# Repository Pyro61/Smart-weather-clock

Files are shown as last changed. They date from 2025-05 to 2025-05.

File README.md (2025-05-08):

# Smart Weather Clock

A real-time clock system with configurable alarms and integrated weather sensing, built on the STM32G474RE microcontroller. Combines internal and external sensors with a simple user interface and Bluetooth-based data expansion.

---

## Project Goals

This project was developed as a learning exercise with the following goals:

- Practice **bare-metal programming** using direct register access on STM32 microcontrollers
- Design the system so that most tasks are handled via **interrupts**, not the main loop — to reduce power consumption
- Learn to build embedded projects using a **build system (CMake)** instead of IDE-generated Makefiles
- Improve fluency with **Git version control** and good repository structure
- Gain experience in **PCB design**

---

## Features

- Real-Time Clock (RTC) with support for a single configurable alarm
- Weather sensing:
  - **Internal sensors**:
    - Temperature & Pressure: LPS25HB (I2C)
    - Humidity: SHT20 (I2C)
  - **External sensors** (via Bluetooth HC-05):
    - Temperature, Pressure, Humidity, Rain Detection
- Periodic weather update every 10 seconds
- Automatic low-power sleep mode:
  - System enters sleep after completing all tasks in the main loop
  - Wakes up on interrupts (e.g., timer or button press)
- User-selectable weather data source (internal or external)
- Alarm notifications:
  - Display alert
  - External buzzer module with built-in sound generator (controlled via GPIO)
- LCD display: 20x4 alphanumeric, driven by HD44780 controller
- User interface:
  - Push-buttons for navigation and settings
  - Potentiometer for adjusting LCD contrast

---

## Hardware Overview

- **Microcontroller**: STM32G474RE
- **Display**: 20x4 LCD with HD44780 controller (parallel interface)
- **Internal Sensors**:
  - LPS25HB (temperature and pressure, I2C)
  - SHT20 (humidity, I2C)
- **External Sensor Module**:
  - Communicates over UART via HC-05 Bluetooth
  - Sends temperature, pressure, humidity, and rain data
- **Buzzer Module**:
  - External buzzer with internal sound generator
  - Controlled via logic-level GPIO
- **User Inputs**:
  - Buttons:
    - OK / Mode
    - Up
    - Down
    - Left
    - Right
  - Potentiometer for LCD contrast

---

## How It Works

1. On startup, the system initializes:
   - MCU embedded peripherals (RTC, UART, GPIO, RTC etc.)
   - Internal sensors
   - LCD

3. Default behavior after power reset:
   - RTC time = 00:00:00
   - Alarm = disabled
   - Weather readings from internal sensors

4. System behavior:
   - Sensor readings are updated every 10 seconds
   - Every second current time and sensor readings are displayed on the screen
   - After processing all events and interrupts, the system enters low-power mode until the next interrupt

5. The default screen shows:
   - Current time
   - Alarm status
   - Sensor data (internal by default)

6. Pressing **OK / Mode** opens a menu with 4 options. The currently selected option is marked with `>` e.g:
```
   > 1. weather indoor  
     2. weather outdoor  
     3. set time  
     4. set alarm
```

7. Navigation:
   - **Up / Down** to move through options
   - **OK / Mode** to select
   - In `Set Time` and `Set Alarm`:
     - **Left / Right** to move between HH:MM:SS
     - **Up / Down** to adjust values

8. Alarm behavior:
   - When alarm is enabled and the current time matches the alarm:
     - "ALARM" screen is displayed
     - Buzzer is activated via GPIO

---

## User Interface

After system startup and peripheral initialization, the main screen displays:
- Current time (reset to 00:00:00 after power-off — no backup battery for RTC)
- Alarm status (disabled after power reset)
- Live weather readings from internal sensors

### Navigation Summary

- **OK / Mode**: Enter menu / confirm selection
- **Up / Down**: Scroll through menu or increment/decrement values
- **Left / Right**: Switch between hours, minutes, seconds

---

## Getting Started

1. Clone this repository.
2. Build the project using CMake
3. Flash the firmware to STM32G474RE (e.g., Nucleo board).
4. Connect all sensors and peripherals according to the labeled connectors on the [custom PCB](pcb/main_board/main_board_pcb.png) or according to [wiring diagram](pcb/main_board/main_board_schematic.png).

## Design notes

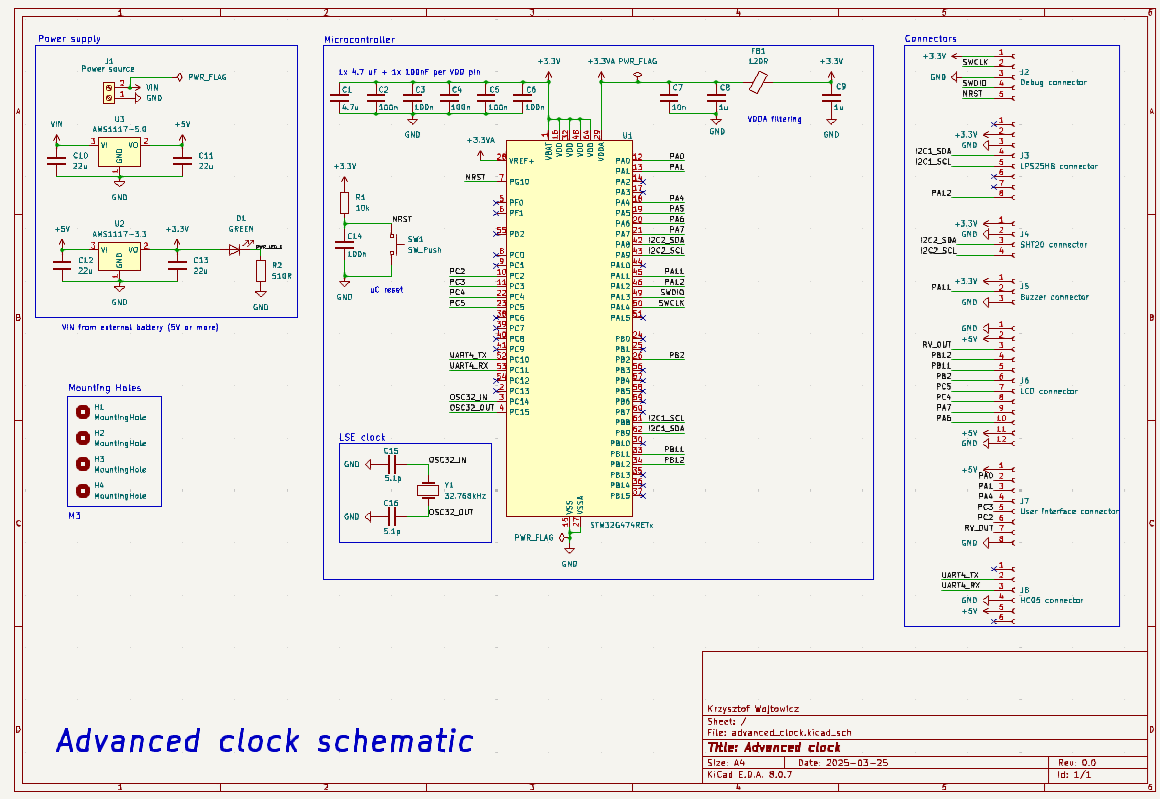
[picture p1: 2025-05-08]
pcb/main_board/main_board_schematic.png

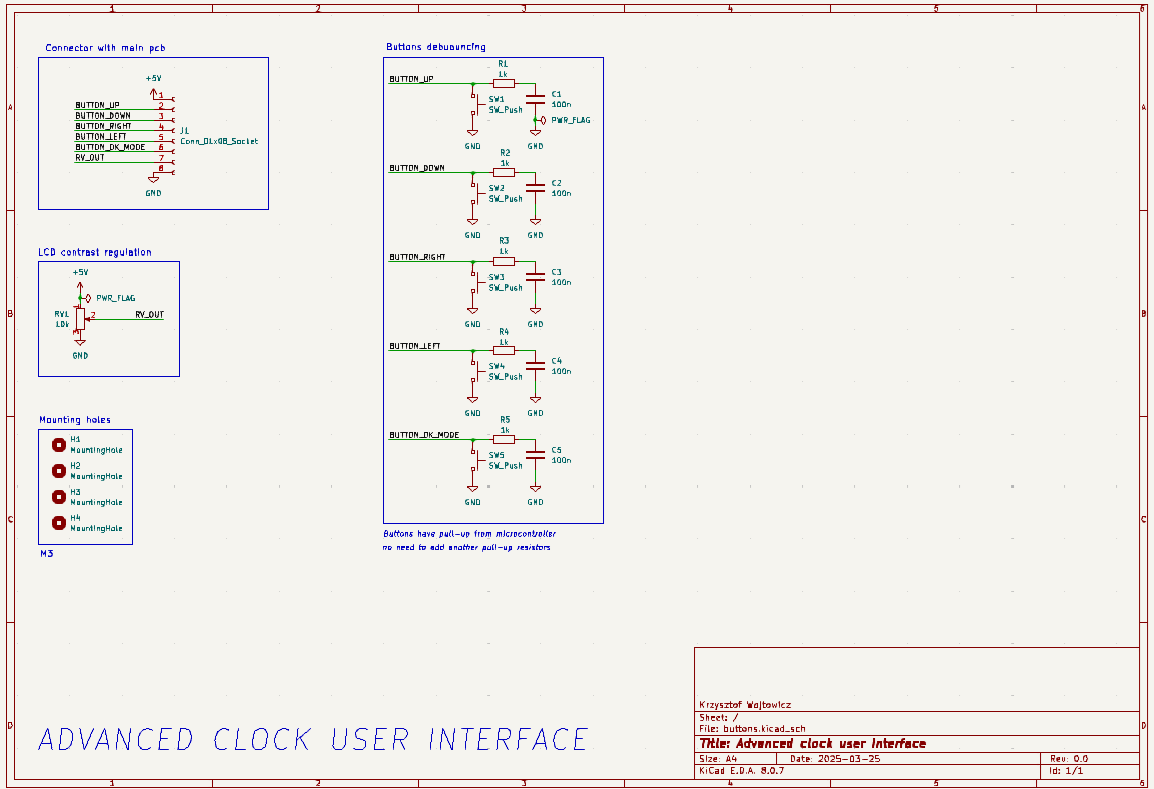
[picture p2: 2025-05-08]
pcb/user_interface_board/user_interface_board_schematic.png

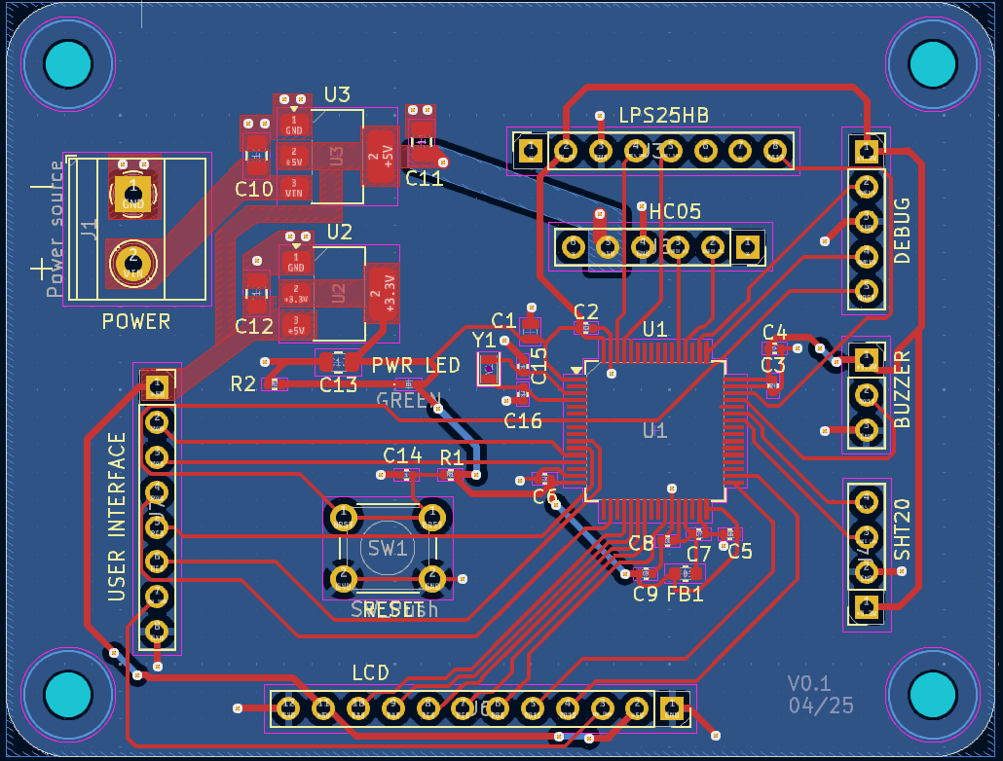
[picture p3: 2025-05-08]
pcb/main_board/main_board_pcb.png

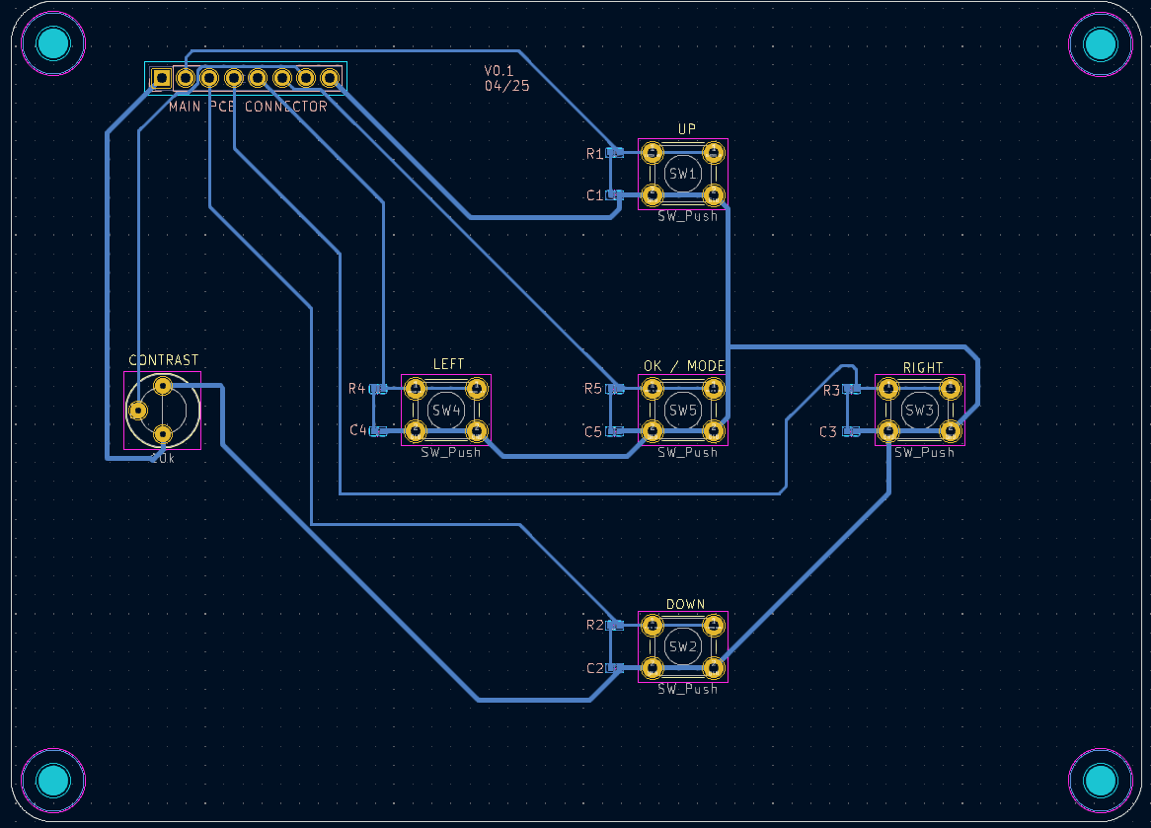
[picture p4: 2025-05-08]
pcb/user_interface_board/user_interface_board_pcb.png

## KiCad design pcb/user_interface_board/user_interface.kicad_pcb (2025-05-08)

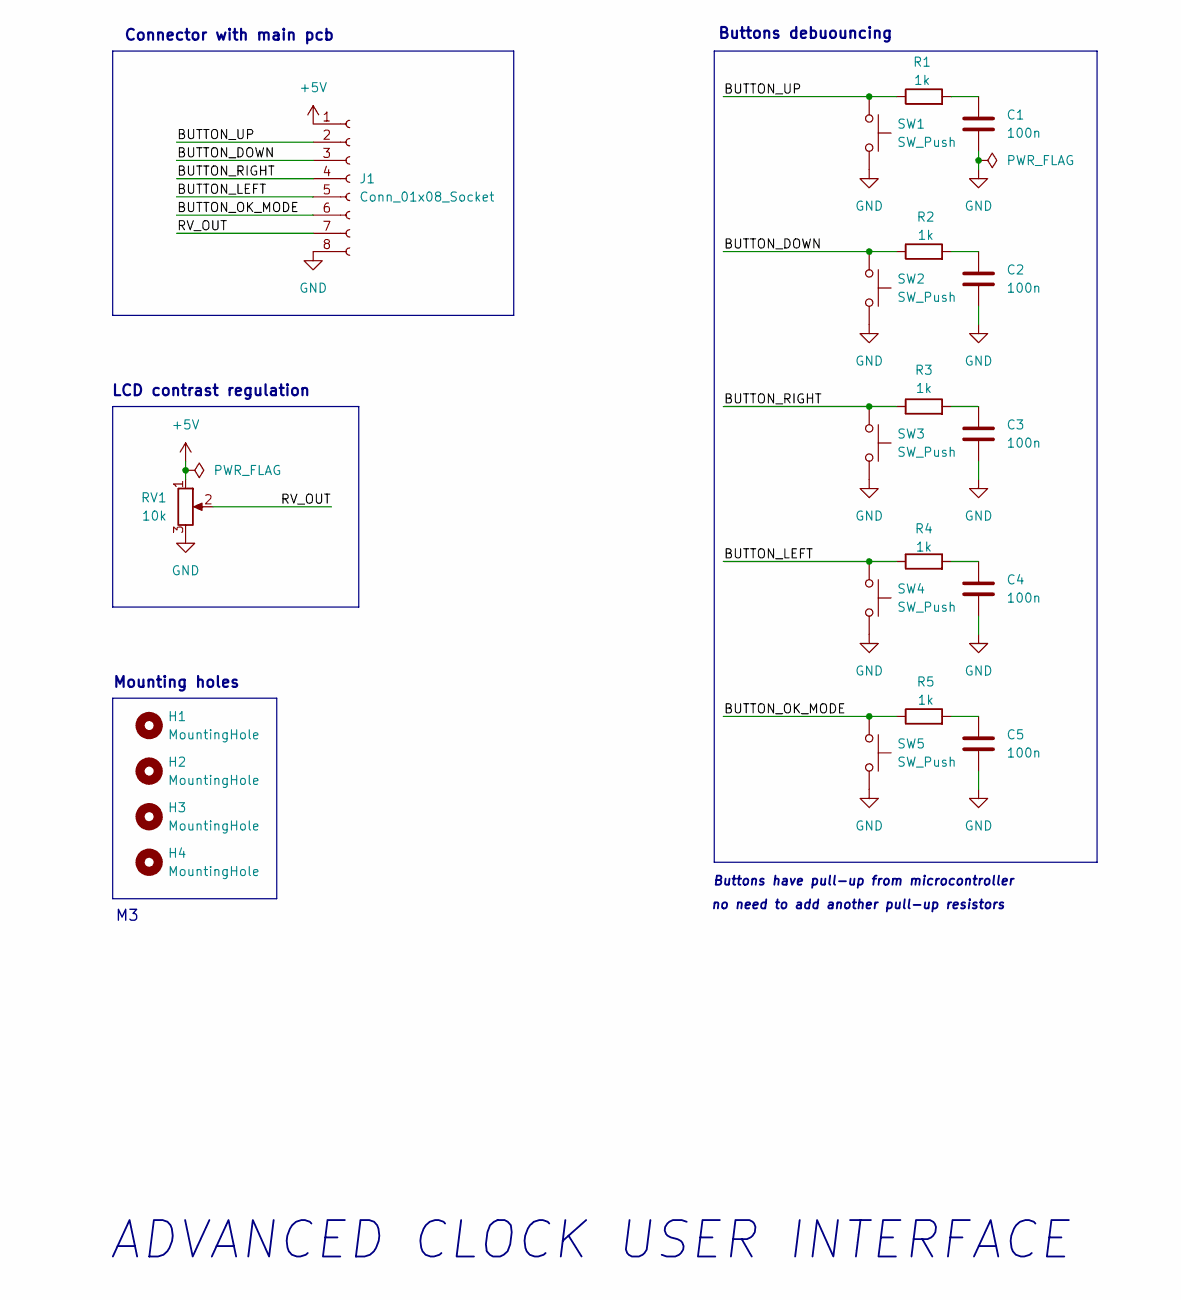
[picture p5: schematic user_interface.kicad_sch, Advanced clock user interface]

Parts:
C1, C2, C3, C4, C5: 100n; C_0402_1005Metric
H1, H2, H3, H4: MountingHole; MountingHole_3.2mm_M3
J1: Conn_01x08_Socket; PinSocket_1x08_P2.54mm_Vertical
R1, R2, R3, R4, R5: 1k; R_0402_1005Metric
RV1: 10k; Potentiometer_Bourns_3339P_Vertical_HandSoldering
SW1, SW2, SW3, SW4, SW5: SW_Push; SW_PUSH_6mm_H7.3mm

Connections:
+5V: J1.1, RV1.1
/BUTTON_DOWN: J1.3, R2.1, SW2.1
/BUTTON_LEFT: J1.5, R4.1, SW4.1
/BUTTON_OK_MODE: J1.6, R5.1, SW5.1
/BUTTON_RIGHT: J1.4, R3.1, SW3.1
/BUTTON_UP: J1.2, R1.1, SW1.1
/RV_OUT: J1.7, RV1.2
GND: C1.2, C2.2, C3.2, C4.2, C5.2, J1.8, RV1.3, SW1.2, SW2.2, SW3.2, SW4.2, SW5.2
unnamed: C1.1, R1.2
unnamed: C2.1, R2.2
unnamed: C3.1, R3.2
unnamed: C4.1, R4.2
unnamed: C5.1, R5.2

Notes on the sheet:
Buttons have pull-up from microcontroller
Mounting holes
LCD contrast regulation
Buttons debuouncing
no need to add another pull-up resistors
Connector with main pcb
ADVANCED CLOCK USER INTERFACE

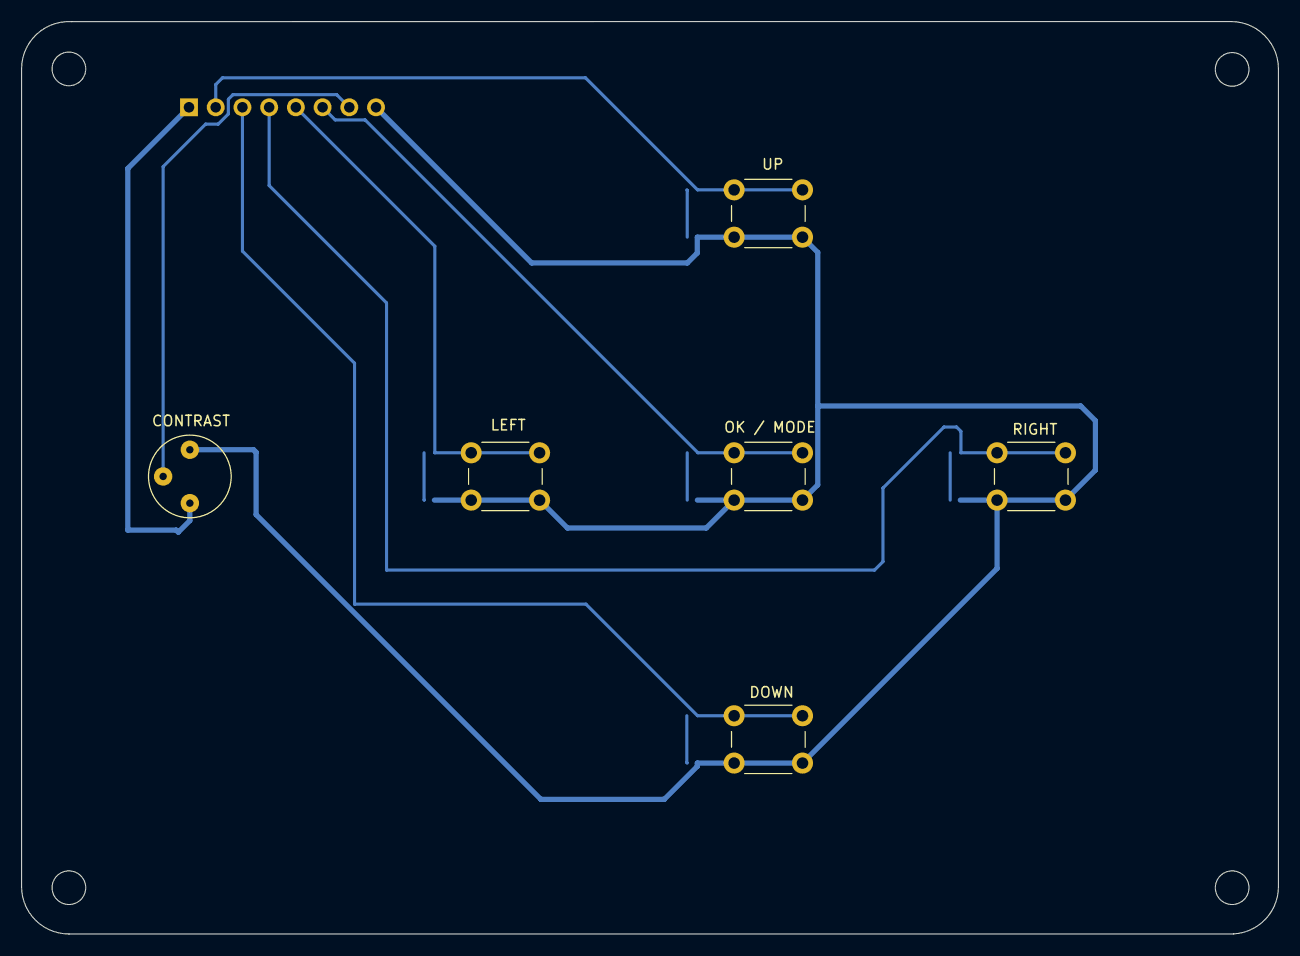
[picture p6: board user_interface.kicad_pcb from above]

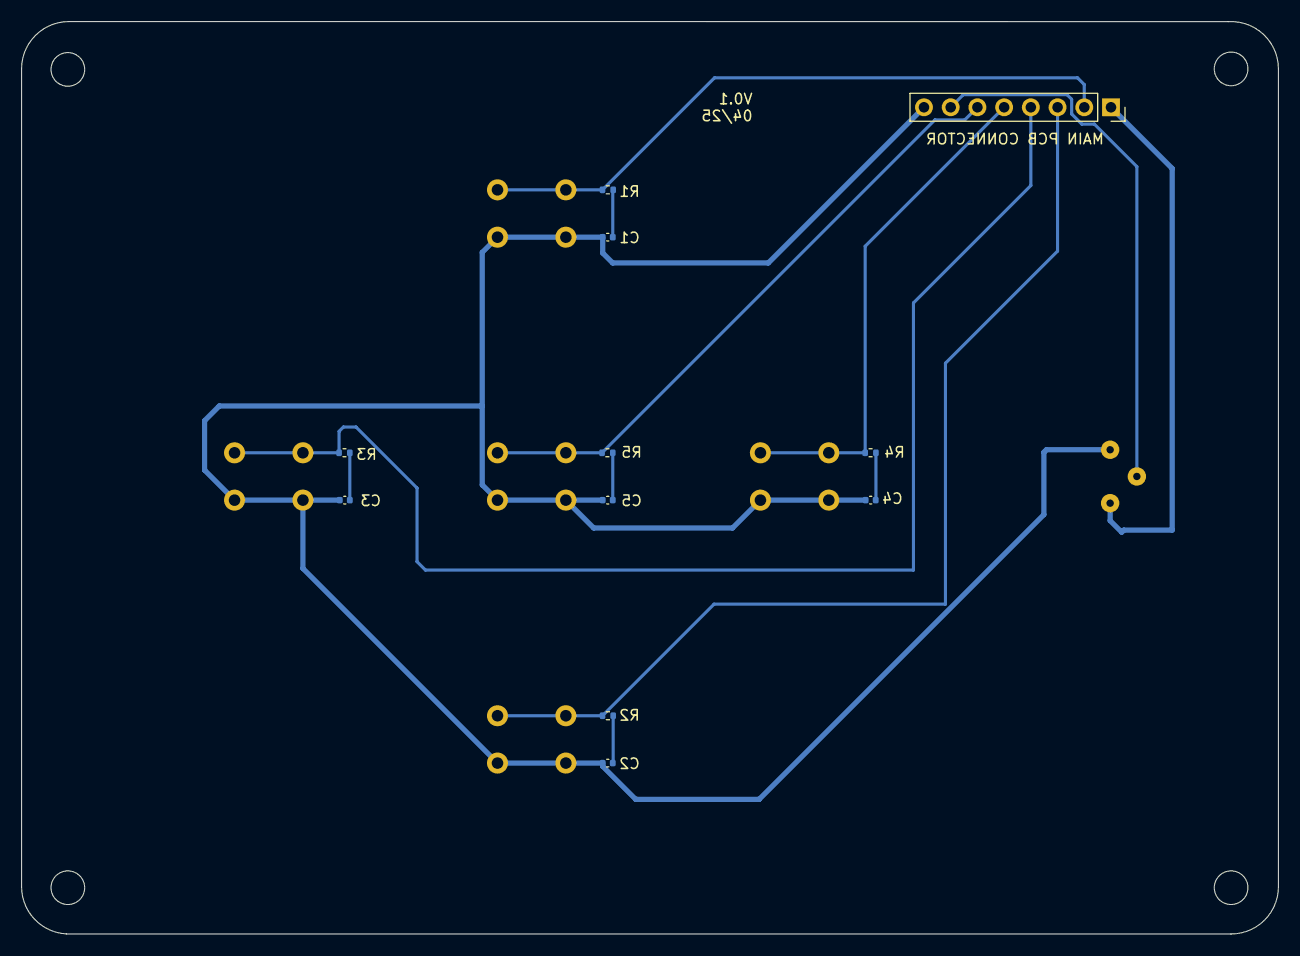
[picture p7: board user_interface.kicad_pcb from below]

Board: 2 copper layers, 119.5 x 86.8 mm, 21 parts (11 on the bottom side), 13 nets.

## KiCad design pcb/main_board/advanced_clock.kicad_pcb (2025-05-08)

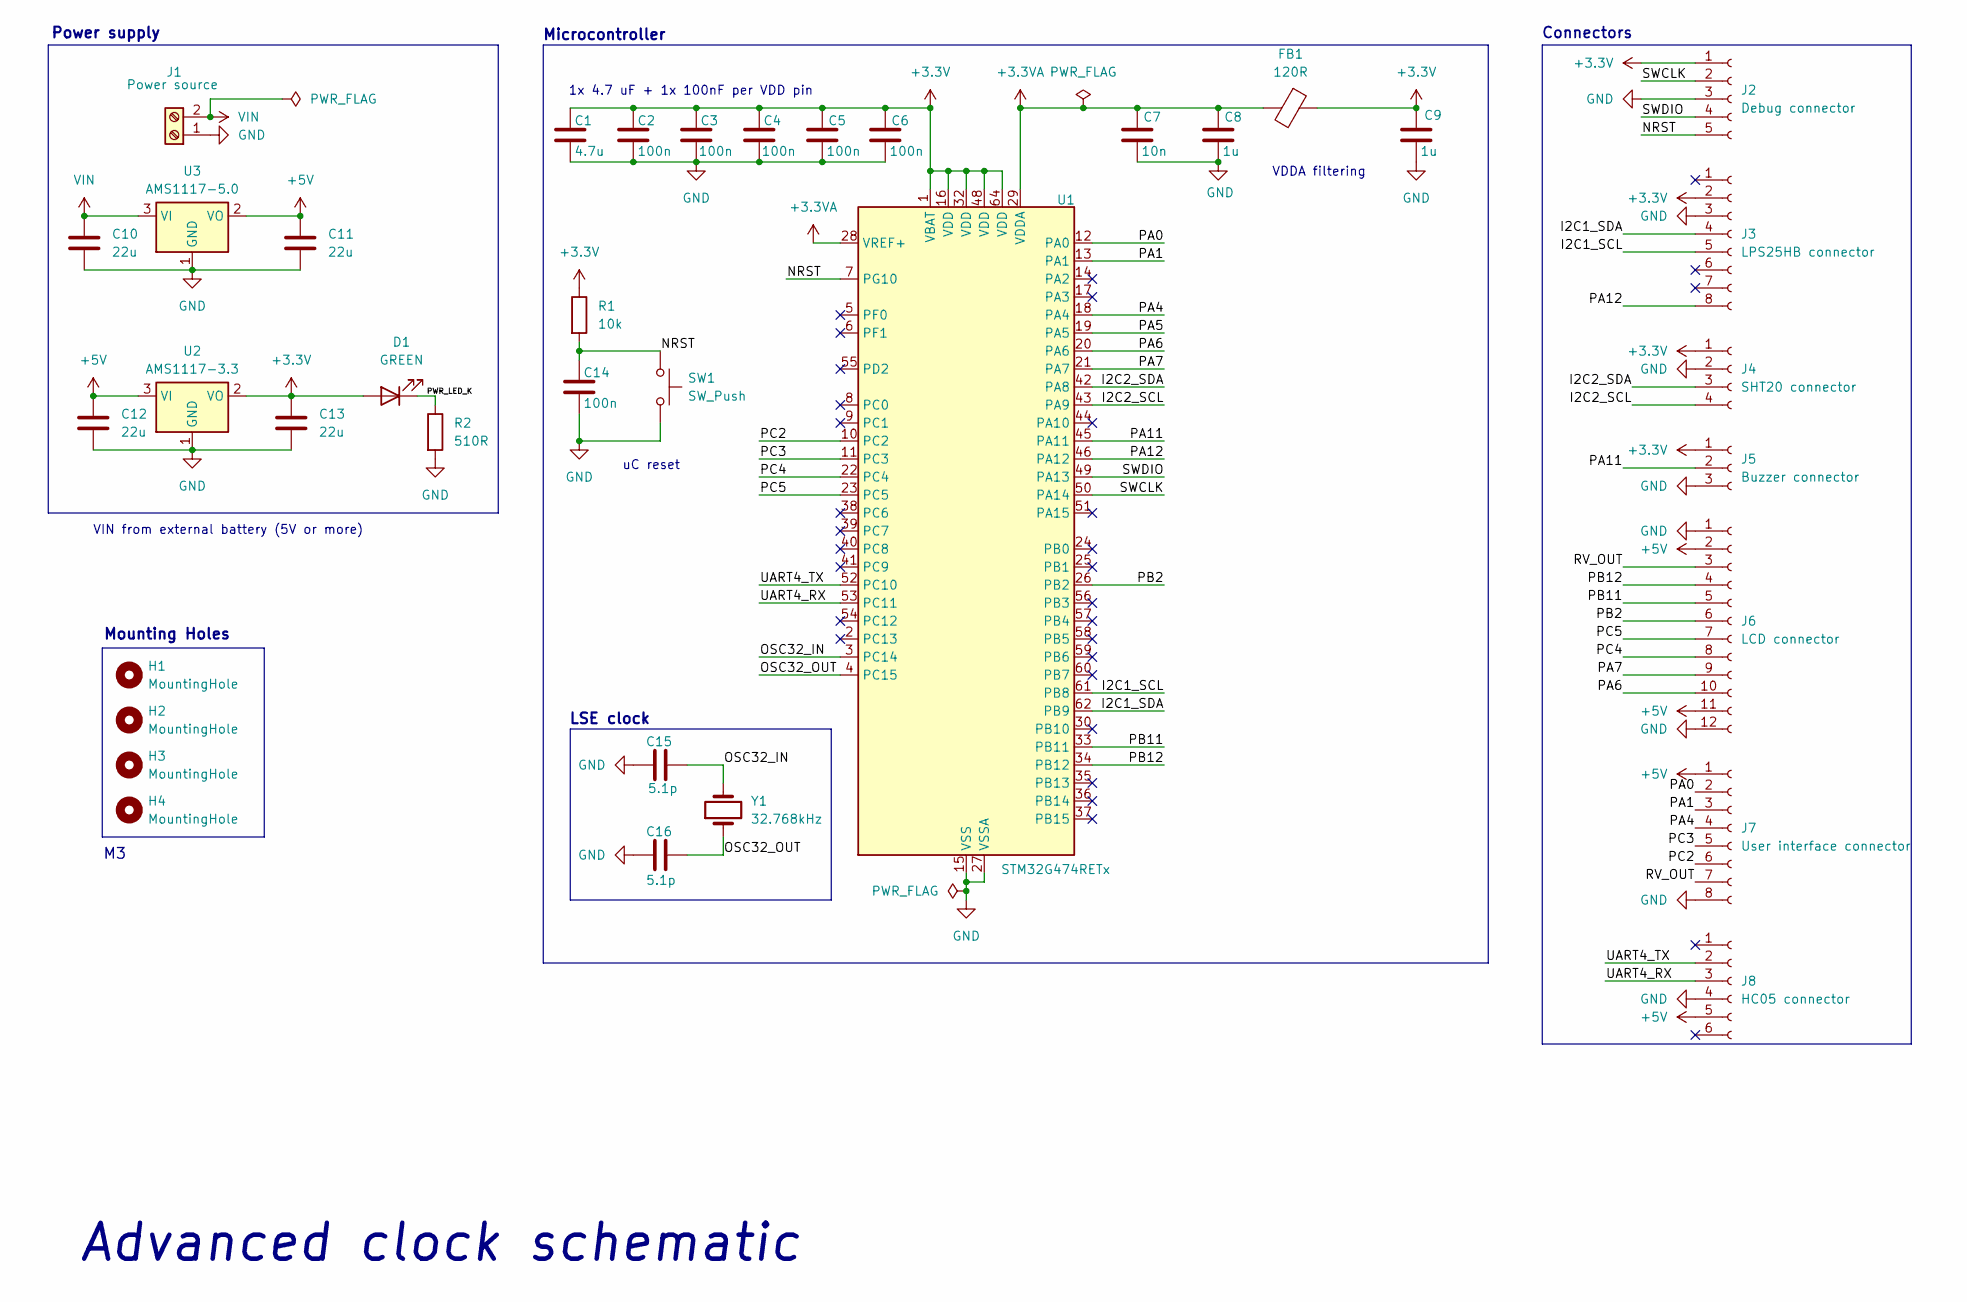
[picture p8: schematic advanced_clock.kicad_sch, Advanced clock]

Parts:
C1: 4.7u; C_0504_1310Metric
C2, C3, C4, C5, C6, C14: 100n; C_0402_1005Metric
C7: 10n; C_0402_1005Metric
C8, C9: 1u; C_0402_1005Metric
C10, C11, C12, C13: 22u; C_0805_2012Metric
C15, C16: 5.1p; C_0402_1005Metric
D1: GREEN; LED_0402_1005Metric
FB1: 120R; L_0603_1608Metric
H1, H2, H3, H4: MountingHole; MountingHole_3.2mm_M3
J1: Power source; TerminalBlock_Phoenix_MKDS-1,5-2-5.08_1x02_P5.08mm_Horizont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
J2: Debug connector; PinSocket_1x05_P2.54mm_Vertical
J3: LPS25HB connector; PinSocket_1x08_P2.54mm_Vertical
J4: SHT20 connector; PinSocket_1x04_P2.54mm_Vertical
J5: Buzzer connector; PinSocket_1x03_P2.54mm_Vertical
J6: LCD connector; PinSocket_1x12_P2.54mm_Vertical
J7: User interface connector; PinSocket_1x08_P2.54mm_Vertical
J8: HC05 connector; PinSocket_1x06_P2.54mm_Vertical
R1: 10k; R_0402_1005Metric
R2: 510R; R_0402_1005Metric
SW1: SW_Push; SW_PUSH_6mm_H7.3mm
U1: STM32G474RETx; LQFP-64_10x10mm_P0.5mm
U2: AMS1117-3.3; SOT-223-3_TabPin2
U3: AMS1117-5.0; SOT-223-3_TabPin2
Y1: 32.768kHz; Crystal_SMD_2012-2Pin_2.0x1.2mm

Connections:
+3.3V: C1.1, C2.1, C3.1, C4.1, C5.1, C6.1, C9.1, C13.1, D1.2 (A), FB1.1, J2.1, J3.2, J4.1, J5.1, R1.1, U1.1 (VBAT), U1.16 (VDD), U1.32 (VDD), U1.48 (VDD), U1.64 (VDD), U2.2 (VO)
+3.3VA: C7.1, C8.1, FB1.2, U1.28 (VREF+), U1.29 (VDDA)
+5V: C11.1, C12.1, J6.2, J6.11, J7.1, J8.5, U2.3 (VI), U3.2 (VO)
/I2C1_SCL: J3.5, U1.61 (PB8)
/I2C1_SDA: J3.4, U1.62 (PB9)
/I2C2_SCL: J4.4, U1.43 (PA9)
/I2C2_SDA: J4.3, U1.42 (PA8)
/NRST: C14.1, J2.5, R1.2, SW1.1, U1.7 (PG10)
/OSC32_IN: C15.2, U1.3 (PC14), Y1.2
/OSC32_OUT: C16.2, U1.4 (PC15), Y1.1
/PA0: J7.2, U1.12 (PA0)
/PA1: J7.3, U1.13 (PA1)
/PA4: J7.4, U1.18 (PA4)
/PA5: U1.19 (PA5)
/PA6: J6.10, U1.20 (PA6)
/PA7: J6.9, U1.21 (PA7)
/PA11: J5.2, U1.45 (PA11)
/PA12: J3.8, U1.46 (PA12)
/PB2: J6.6, U1.26 (PB2)
/PB11: J6.5, U1.33 (PB11)
/PB12: J6.4, U1.34 (PB12)
/PC2: J7.6, U1.10 (PC2)
/PC3: J7.5, U1.11 (PC3)
/PC4: J6.8, U1.22 (PC4)
/PC5: J6.7, U1.23 (PC5)
/PWR_LED_K: D1.1 (K), R2.1
/RV_OUT: J6.3, J7.7
/SWCLK: J2.2, U1.50 (PA14)
/SWDIO: J2.4, U1.49 (PA13)
/UART4_RX: J8.3, U1.53 (PC11)
/UART4_TX: J8.2, U1.52 (PC10)
GND: C1.2, C2.2, C3.2, C4.2, C5.2, C6.2, C7.2, C8.2, C9.2, C10.2, C11.2, C12.2, C13.2, C14.2, C15.1, C16.1, J1.1, J2.3, J3.3, J4.2, J5.3, J6.1, J6.12, J7.8, J8.4, R2.2, SW1.2, U1.15 (VSS), U1.27 (VSSA), U1.31 (VSS), U1.47 (VSS), U1.63 (VSS), U2.1 (GND), U3.1 (GND)
VIN: C10.1, J1.2, U3.3 (VI)

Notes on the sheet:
1x 4.7 uF + 1x 100nF per VDD pin
Mounting Holes
uC reset
Power supply
VDDA filtering
VIN from external battery (5V or more)
LSE clock
Connectors
Microcontroller
Advanced clock schematic

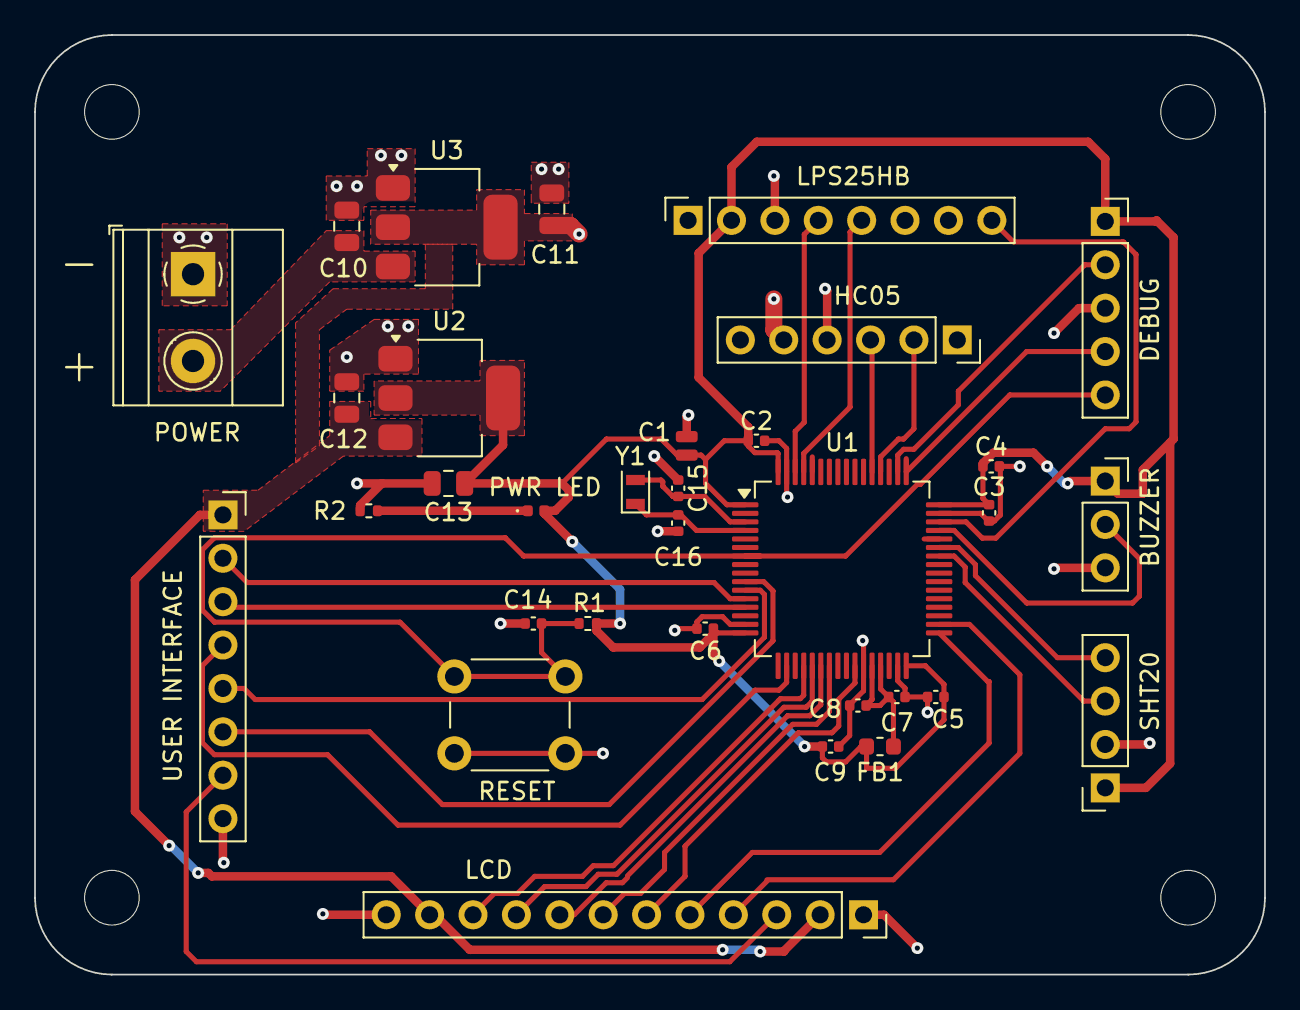
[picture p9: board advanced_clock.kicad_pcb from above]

Board: 2 copper layers, 72.0 x 55.0 mm, 37 parts (0 on the bottom side), 32 nets.

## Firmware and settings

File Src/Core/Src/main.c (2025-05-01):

#include "../Inc/main.h"
#include "../../hw/mcu_hw/mcu_hw_init.h"
#include "../../hw/external_hw/external_hw_init.h"
#include "../../logic_init.h"
#include "../../hw/mcu_hw/iwdg/iwdg.h"
#include "../../hw/mcu_hw/low_power/low_power.h"


int main(void)
{
    /* Hw initialisation */
    mcu_hw_init();
    external_hw_init();

    /* Application logic initialisation */
    logic_init();
    
    /* Loop forever */
	while (1)
    {
        sleep();
        iwdg_feed_counter();
    }
}

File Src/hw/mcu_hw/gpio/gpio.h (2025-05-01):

#pragma once

#include "stdint.h"


/* EXTI callback function typedef */
typedef void (*cb_t)(void);

/* Enums with gpio config options */
enum gpio_port
{
    START_PORT = 0,
    PORT_A = 0,
    PORT_B = 1,
    PORT_C = 2,
    PORT_D = 3,
    PORT_E = 4,
    PORT_F = 5,
    PORT_G = 6,
    END_PORT = 6
};

enum gpio_mode
{
    START_MODE = 0,
    INPUT = 0,
    OUTPUT = 1,
    ALTERNATE_FUN = 2,
    ANALOG = 3,
    END_MODE = 3
};

enum gpio_pp_od
{
    START_PP_OD = 0,
    PUSH_PULL = 0,
    OPEN_DRAIN = 1,
    END_PP_OD = 1
};

enum gpio_speed
{
    START_SPEED = 0,
    SPEED_LOW = 0,
    SPEED_MEDIUM = 1,
    SPEED_HIGH = 2,
    SPEED_VERY_HIGH = 3,
    END_SPEED = 3
};

enum gpio_pull
{
    START_PULL = 0,
    NO_PULL = 0,
    PULL_UP = 1,
    PULL_DOWN = 2,
    END_PULL = 2
};

enum gpio_state
{
    STATE_ERR = -1,
    LOW = 0,
    HIGH = 1
};

enum gpio_err
{
    ERR = -1,
    NO_ERR = 0
};

enum exti_trigger
{
    START_TRIG = 0,
    RISING_EDGE = 0,
    FALLING_EDGE = 1,
    BOTH_EDGES = 2,
    END_TRIG = 2
};


enum gpio_err gpio_set_af(enum gpio_port port, uint8_t pin, uint8_t af);
enum gpio_err gpio_config(enum gpio_port port, uint8_t pin, uint8_t mode, uint8_t pp_od, uint8_t pull, uint8_t speed);
enum gpio_err gpio_set_exti(enum gpio_port port, uint8_t pin, enum exti_trigger trig, cb_t cb);
enum gpio_err gpio_output_write(enum gpio_port port, uint8_t pin, enum gpio_state state);
enum gpio_state gpio_input_read(enum gpio_port port, uint8_t pin);

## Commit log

2024-12-31 test: add unity framework files
2024-12-31 Src: add drivers files
2024-12-31 src: add weather sensors module files
2025-01-08 drivers: add missing stdint include
2025-01-08 spi: create source files
2025-01-08 src: add spi.c to compilation
2025-01-08 spi: add init function implementation
2025-01-11 spi: add write polling function implementation
2025-01-11 spi: write dma recv function implementation
2025-01-11 spi: change multiple requests handling mechanism
    So far it was checking bus state bit is spi status register, now it's variable indicating currect spi state. Higher logic modules than want to use spi, must first check if is spi bus free, then use w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
2025-01-19 i2c: add implementation
    init, write/read polling, read dma
2025-01-19 mcu_hw: add i2c1_init to init
2025-01-19 gpio: fix set af fun
    It wasn't writing af for pins 8 and above
    [gpio.c]
2025-01-19 i2c: fix
2025-01-19 i2c: separate i2c1 and i2c2 code spaces
2025-02-02 i2c: add i2c2 implementation
2025-02-02 aht15: add implementation
    -init
    -measuring trigger
    -get humidity
    -get temperature
2025-02-02 aht15: change implementation
    calls tim_meas_no_block with 80ms measurement inside aht15_trigger_measurement fun, after that time data is read from sensor
2025-02-03 uart: add implementation of uart4
2025-02-03 mcu_hw: add uart4 to init
2025-02-08 events: add buttons pressed, refresh and alarm event names
2025-02-13 alarm: add function prototypes
    needed in handling weather in/out states
2025-02-13 time: add function prototypes
    needed in weather in/out state handling
2025-02-15 main state machine: change state switching logic
    bypassing mode selection when switching modes, so for example after when exiting weather in mode to set alarm via mode selection come back directly to weather in bypassing mode selection
2025-02-15 state set time: fix failing test
    Reading next position from set_time_parts_buf_position array instead of current
2025-02-16 set time unit test: add reading display buffer in press left/right button
2025-02-16 state set time: fix implementation
    Add preparing buffer and printing display in right/left button state reactions
2025-03-06 buttons: add implementation
2025-03-09 rain sensor: add implementation
2025-03-09 adapter sys comm: change copy data from buf fun prototype name
2025-03-09 rtc: fix wakeup timer irq not called bug
2025-03-09 HD44780: fix writing not always from position 0,0 bug
    [HD44780.c]
2025-03-09 weather in: fix implementation
    - change buf positions
    - add display functions holder to const pointer
    - add printing blank sign instead of minus sign if temp is greater / equal 0
    - print "NO DATA" instead of " DATA" if rain sensor is not applied
    - change buf positions in time saving to buffer
2025-03-10 i2c: change irqs priority
2025-03-18 sht20: add implementation
    replace aht15 with sht20 because aht15stopped working
    [sht20.c]
2025-03-18 i2c: add dmamux clock enable in i2c init functions, change order of writing i2c2 registers in write polling
2025-03-18 uart: change dma channgel using in uart4
2025-05-01 low power: add implementation
2025-05-01 buzzer: change pins due to pcb desing
2025-05-01 HD44780: change pins due to pcb desing
2025-05-02 datasheets: add mcu and external devices datasheets
2025-05-02 pcb: add kicad files and pcb/schematic screens
    [advanced_clock.kicad_pcb, advanced_clock.kicad_sch, user_interface.kicad_pcb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]
2025-05-08 Update README.md
    Add link to pcb desing screen
